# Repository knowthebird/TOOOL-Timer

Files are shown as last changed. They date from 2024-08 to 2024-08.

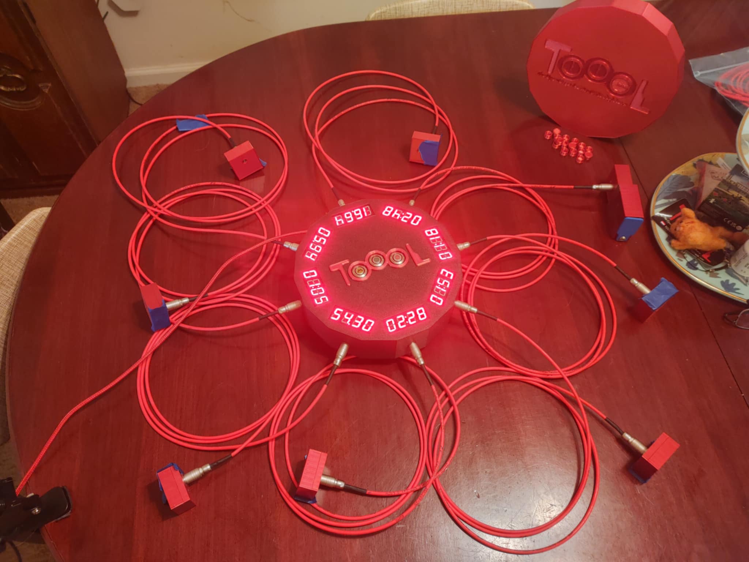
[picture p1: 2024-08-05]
Graphics/Testing-Assembly.jpg

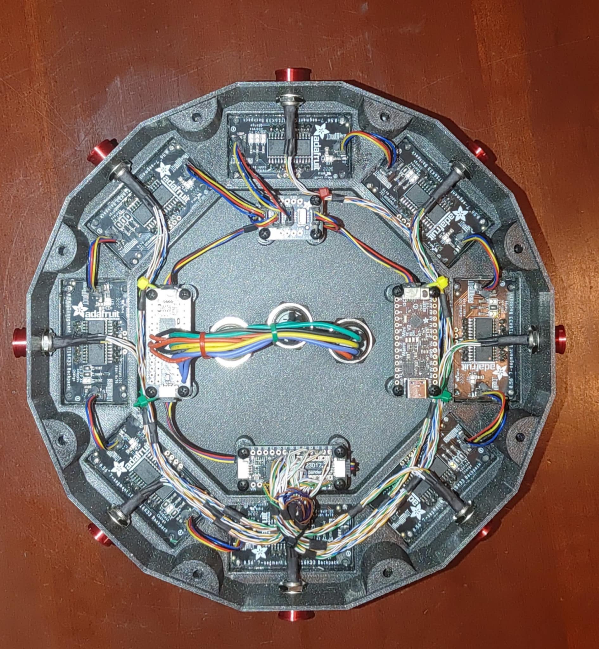
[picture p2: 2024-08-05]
Graphics/Internal-Wiring.jpg

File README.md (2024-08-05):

# TOOOL-Timer
Timer for The Open Organization Of Lockpickers (TOOOL) for Lock Picking games and competitions. 

Initially designed with TOOL DMV chapters for use with up to 8 players using TOOOLs red Kik Locks.

A youtube video covering the basics of how it works can be seen here:

Watch the video (https://youtu.be/ACWqIDEtgrU)

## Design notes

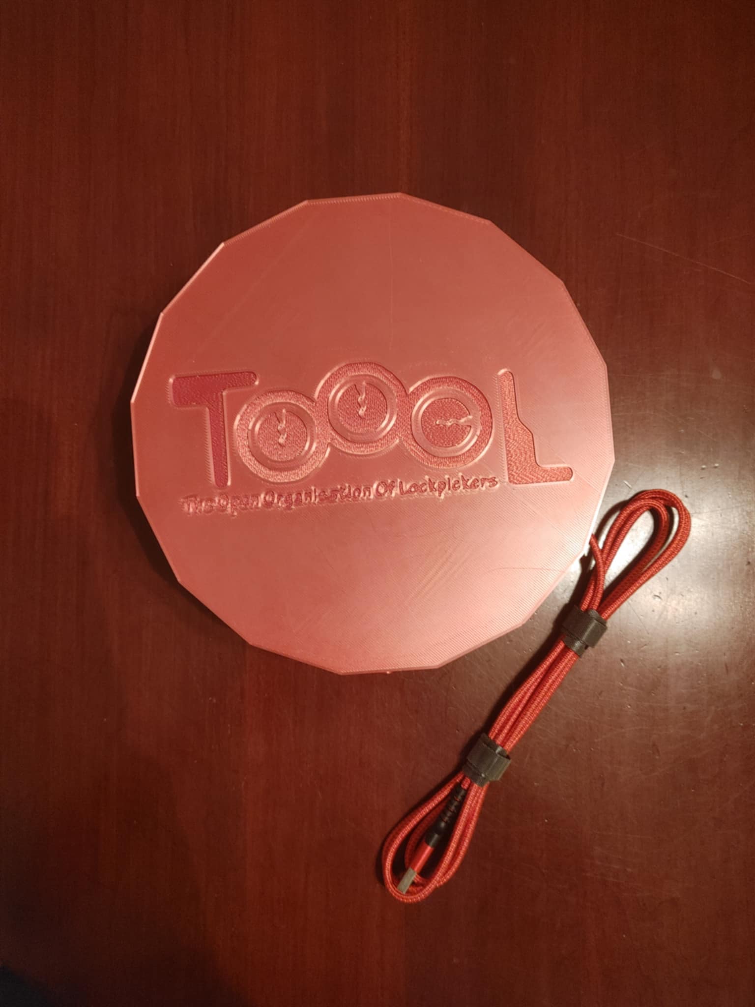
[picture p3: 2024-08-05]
Graphics/WIth-Cover.jpg

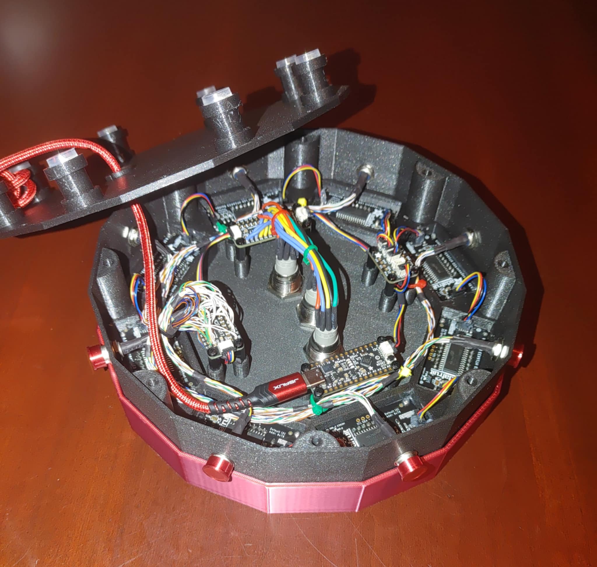
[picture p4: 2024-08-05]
Graphics/Power-Data-Cable.jpg

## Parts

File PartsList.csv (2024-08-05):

Used For | Manufacturer or Supplier Part Number | Description | Manufacturer or Supplier | Quanity | Cost per Unit | Total Cost | Link
Lock | Red KiKlock | Red KiK-lock Padlock | TOOOL | 8 | $30.00 | $240.00 | https://www.toool.us/equipment/Red-KiK-lock-p519912395/
Timer | 5625 | Qwiic / Stemma QT 5 Port Hub | Adafruit | 1 | $2.50 | $2.50 | https://www.adafruit.com/product/5625
Timer | 5346 | MCP23017 I2C GPIO Expander Breakout - STEMMA QT / Qwiic | Adafruit | 2 | $5.95 | $11.90 | https://www.adafruit.com/product/5346
Timer | 559 | Rugged Metal Pushbutton with Red LED Ring - 16mm | Adafruit | 3 | $4.95 | $14.85 | https://www.adafruit.com/product/559
Timer | 2590 | Metro Mini 328 V2 - Arduino-Compatible - 5V 16MHz | Adafruit | 1 | $14.95 | $14.95 | https://www.adafruit.com/product/2590
Timer | 877 | 7-Segment LED Matrix Backpack - STEMMA QT / qwiic | Adafruit | 8 | $6.95 | $55.60 | https://www.adafruit.com/product/877
Timer | 865 | Red 7-segment clock display - 0.56" digit height | Adafruit | 8 | $3.95 | $31.60 | https://www.adafruit.com/product/865
Timer | 4210 | STEMMA QT / Qwiic JST SH 4-pin Cable - 100mm Long | Adafruit | 3 | $0.95 | $2.85 | https://www.adafruit.com/product/4210
Timer | 4399 | STEMMA QT / Qwiic JST SH 4-Pin Cable - 50mm Long | Adafruit | 8 | $0.95 | $7.60 | https://www.adafruit.com/product/4399
Lock | HR10-7R-4SA(73) | CONN RCPT FMALE 4POS GOLD SOLDER | Hirose | 8 | $15.55 | $124.40 | https://www.digikey.com/en/products/detail/hirose-electric-co-ltd/HR10-7R-4SA-73/
Timer | HR10-7R-4S(73) | CONN RCPT FMALE 4P GOLD SLDR CUP | Hirose | 8 | $16.26 | $130.08 | https://www.digikey.com/en/products/detail/hirose-electric-co-ltd/HR10-7R-4S-73/1095427
Cables | HR10-7P-4P(73) | CONN PLUG MALE 4P GOLD SLDR CUP | Hirose | 16 | $14.61 | $233.76 | https://www.digikey.com/en/products/detail/hirose-electric-co-ltd/HR10-7P-4P-73/896581
Cables / Timer | MM-C6R-06.5-28LSZH-F | THIN CAT6 28AWG UTP LSZH 6.5 RED | Pactech | 12 | $8.11 | $97.32 | https://www.digikey.com/en/products/detail/pactech/MM-C6R-06-5-28LSZH-F/14005003
Lock | D2A-1110 | SWITCH SNAP ACTION SPDT 0.1A 30V | Omron Electronics | 8 | $1.77 | $14.16 | https://www.digikey.com/en/products/detail/omron-electronics-inc-emc-div/D2A-1110/699999
Lock | Lock Switch PCB | PCB for Lock Switch and Connector (set of 8+1 spare) | OSH Park | 1 | $4.20 | $4.20 | https://oshpark.com/shared_projects/PHDMdzFt
Timer | TYCNZ-2 | USB A to USB C Charger Cord 3.1A Fast Charging 2-Pack 6.6ft | JAUX | 1 | $6.92 | $6.92 | https://www.amazon.com/gp/product/B076FPGWNZ
Timer | DS-WSD300 | Clear Self Adhesive Rubber Bumpers Pads 13mm diameter x 4mm | Amazon | 8 | $0.04 | $0.32 | https://www.amazon.com/dp/B087MG3G76/
Timer | B0BK18R23P | Nylon Standoff Male to Female M2.5 10mm+6mm Black | Amazon | 16 | $0.20 | $3.20 | https://www.amazon.com/dp/B0BK18R23P
Timer | 92492A711 | Nylon Pan Head Phillips Screw M2.5 x 6mm Black | McMASTER-CARR | 16 | $0.02 | $0.32 | https://www.mcmaster.com/92492A711
Timer | 90925A148 | Torx Rounded Head Screw Number 6 Size 1/2" Long | McMASTER-CARR | 8 | $0.20 | $1.60 | https://www.mcmaster.com/90925A148/
Timer | 93802A221 | 18-8 Pan Head Phillips Screw 0-80 Thread 1/4" Long | McMASTER-CARR | 32 | $0.07 | $2.24 | https://www.mcmaster.com/91772A055/
Lock | 91292A115 | 18-8 Socket Head Screw M3 x 0.5 mm 16 mm Long | McMASTER-CARR | 8 | $0.07 | $0.57 | https://www.mcmaster.com/91292A115/
Lock | 91828A211 | 18-8 Hex Nut M3 x 0.5 mm Thread | McMASTER-CARR | 8 | $0.05 | $0.40 | https://www.mcmaster.com/91828A211/
Timer | Timer-Assembly-Casing | Main casing for timer and electronics | NA - 3D Printed | 1 | - | - | -
Timer | Timer-Assembly-Casing-Logo-Insert | TOOOL Logo insert for main casing | NA - 3D Printed | 2 | - | - | -
Timer | Timer-Assembly-Floor-Panel | Floor panel to seal main casing | NA - 3D Printed | 1 | - | - | -
Timer | Timer-Assembly-Floor-Panel-Grommet | Grommet to place on power cable and into floor panel | NA - 3D Printed | 2 | - | - | -
Timer | Timer-Assembly-Casing-Lid-Cover | Cover to protect top of casing surface in transit | NA - 3D Printed | 1 | - | - | -
Lock | Lock-Assembly-Shackle-Side | Lock casing covering shackle | NA - 3D Printed | 8 | - | - | -
Lock | Lock-Assembly-Connector-Side | Lock casing covering connector | NA - 3D Printed | 8 | - | - | -
Lock / Timer | Receptacle-Cover | Covers to protect receptacles when not in use | NA - 3D Printed | 16 | - | - | -
Cables / Timer | MP-H002-04-156 | Assorted Sizes of Heat Shrink Tubing | Amazon | As Needed | - | $8.79 | https://www.amazon.com/gp/product/B07QM8249H/
Timer | B07T4SYVYG | 22 AWG Stranded Wire Kit Silicone 6 Colors 7m Each Spool | Amazon | As Needed | - | $16.95 | https://www.amazon.com/gp/product/B07T4SYVYG/
Lock / Cables / Timer | 3096525-M | Multicore Solder Wire 180 C | Loctite | As Needed | - | $56.99 | https://www.amazon.com/gp/product/B00DKF13JY/
Timer | 908570 | Clear Silicone Waterproof Sealant | Loctite | As Needed | - | $9.13 | https://www.amazon.com/dp/B0002BBX3U/
Lock / Timer | PLA-1.75-SILKY-RED | PLA Filament 1.75mm Shining Red | ZIRO | As Needed | - | $20.99 | https://www.amazon.com/gp/product/B08BG6ZPF1/
Timer | Prusament PLA Galaxy Black | PLA Filament 1.75mm Galaxy Black | PRUSA | As Needed | - | $29.99 | https://www.prusa3d.com/product/prusament-pla-prusa-galaxy-black-1kg/
 |  |  |  |  | TOTAL | $1,144.18

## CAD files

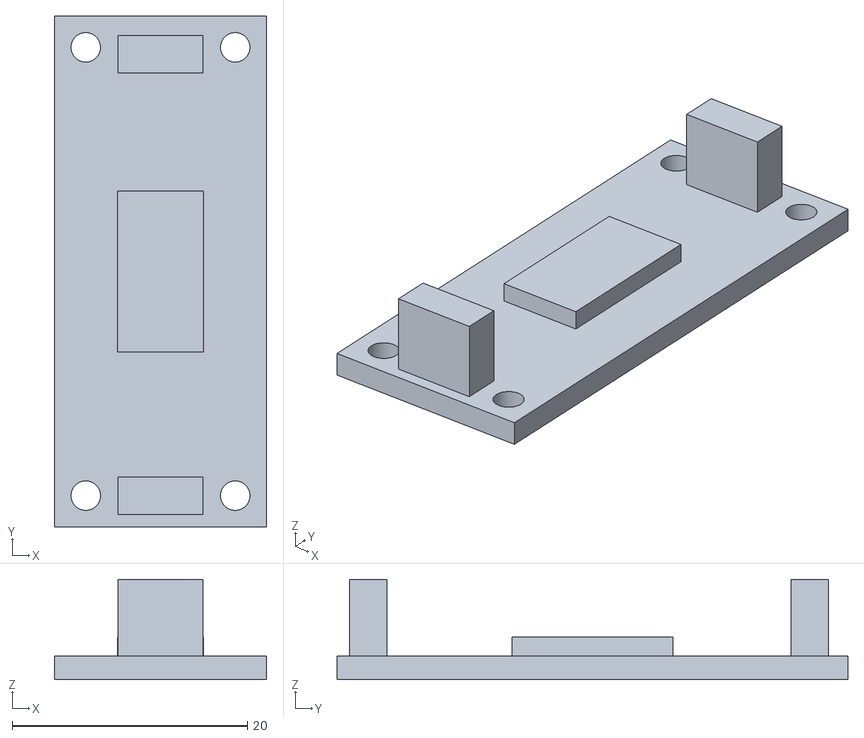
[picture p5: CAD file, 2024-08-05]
3dModels/Internal-Components/Adafruit-MCP23017-PCB-main.stl
18.0 x 43.4 x 8.50

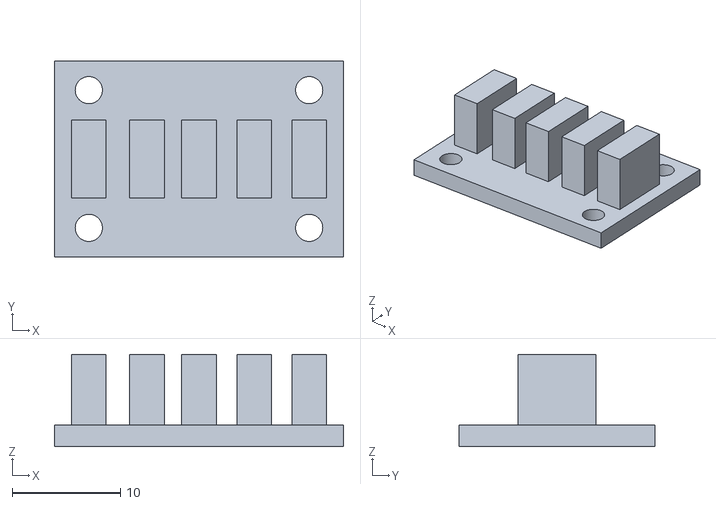
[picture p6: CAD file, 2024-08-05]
3dModels/Internal-Components/Adafruit-Qwiic-Stemma-QT-5-Port-Hub-PCB-main.stl
26.7 x 18.0 x 8.50

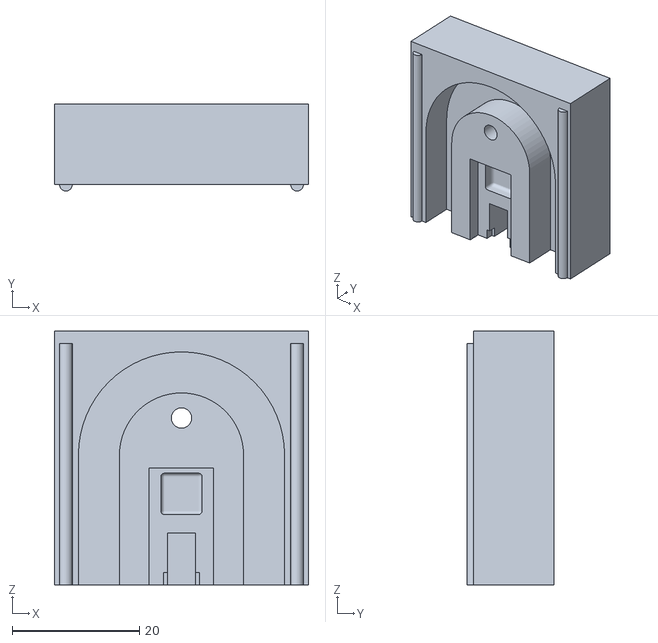
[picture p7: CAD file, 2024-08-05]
3dModels/Lock-Assembly/Shackle-Side.stl
40.0 x 13.7 x 40.0

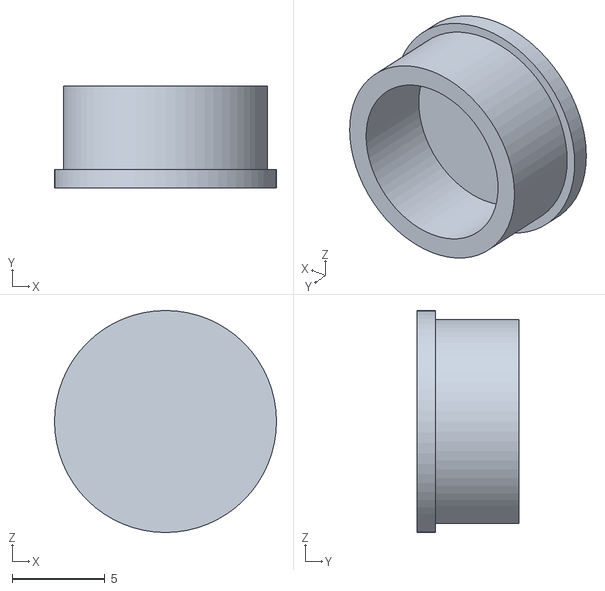
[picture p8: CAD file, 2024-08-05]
3dModels/Receptacle-Cover.stl
12.0 x 5.50 x 12.0

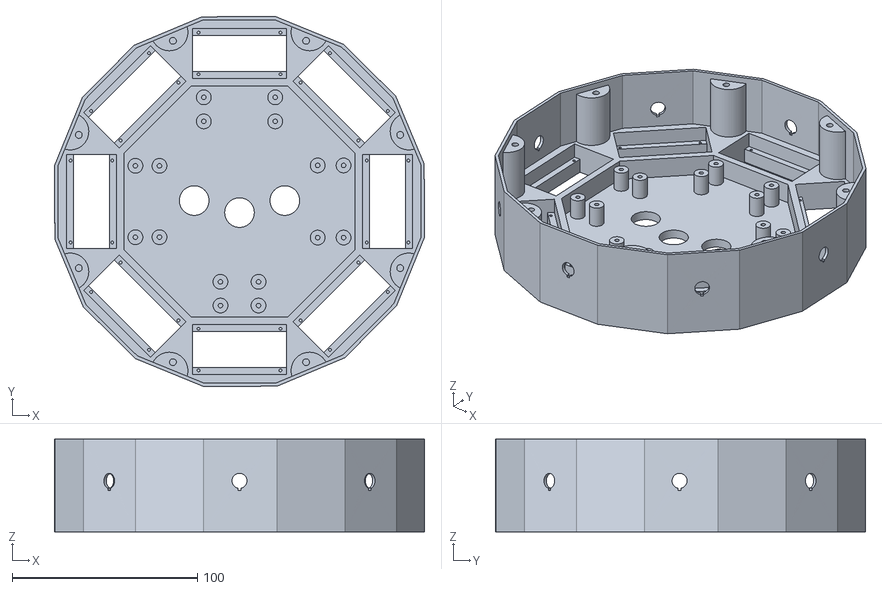
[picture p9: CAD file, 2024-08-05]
3dModels/Timer-Assembly/Casing.stl
200.0 x 200.0 x 50.0

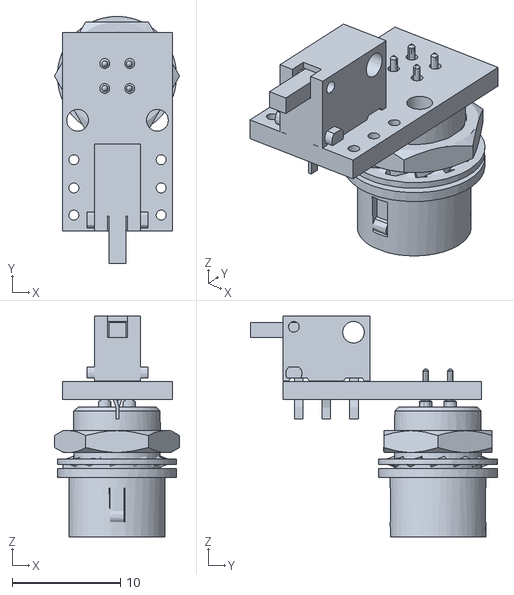
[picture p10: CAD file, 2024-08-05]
3dModels/Internal-Components/LockSwitchPCB.stl
11.5 x 22.8 x 20.4

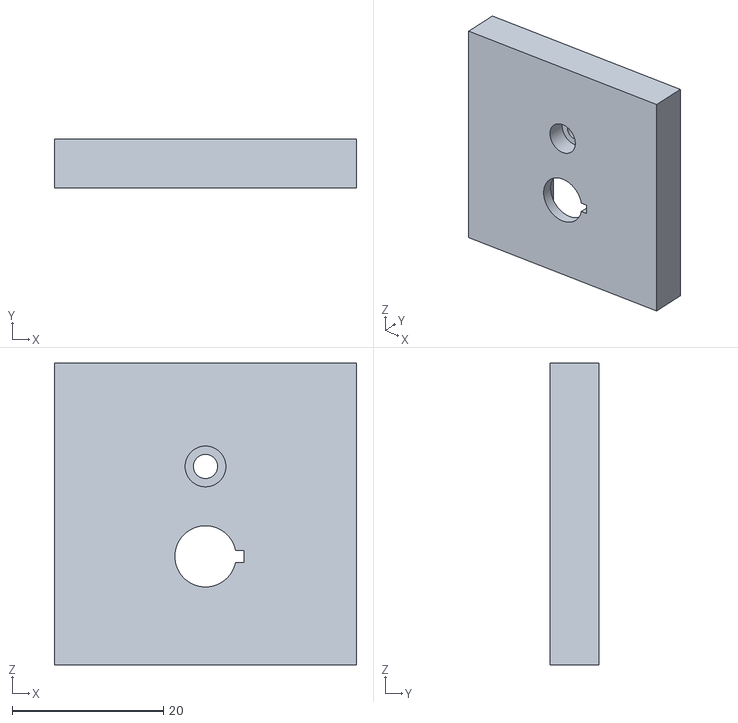
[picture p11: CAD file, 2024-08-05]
3dModels/Lock-Assembly/Connector-Side.stl
40.0 x 6.45 x 40.0

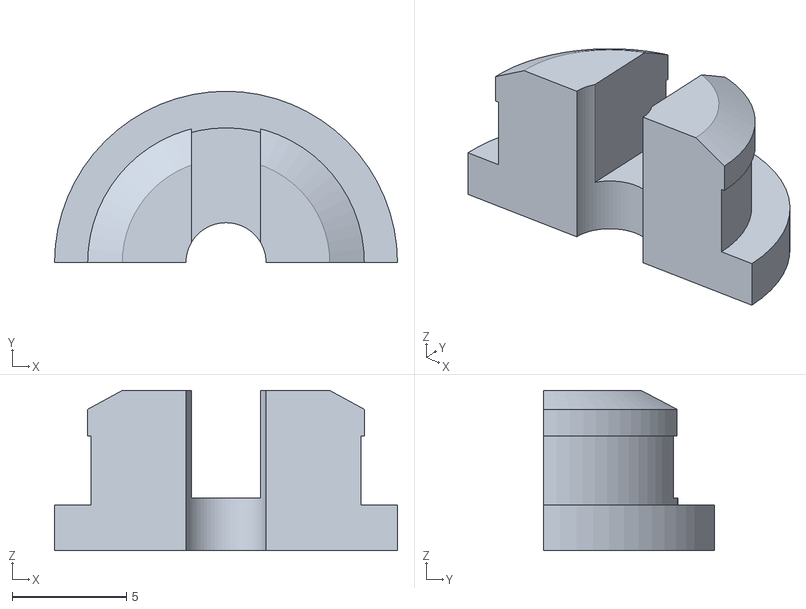
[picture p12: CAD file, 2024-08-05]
3dModels/Timer-Assembly/Floor-Panel-Grommet.stl
15.0 x 7.50 x 7.00

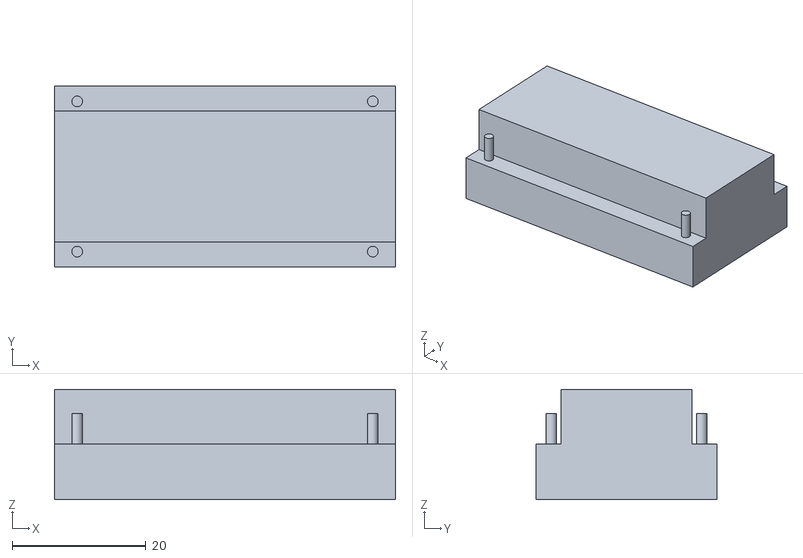
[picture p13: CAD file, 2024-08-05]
3dModels/Internal-Components/7-Seg-And-I2C-Driver-Cutout.stl
51.1 x 27.1 x 16.5

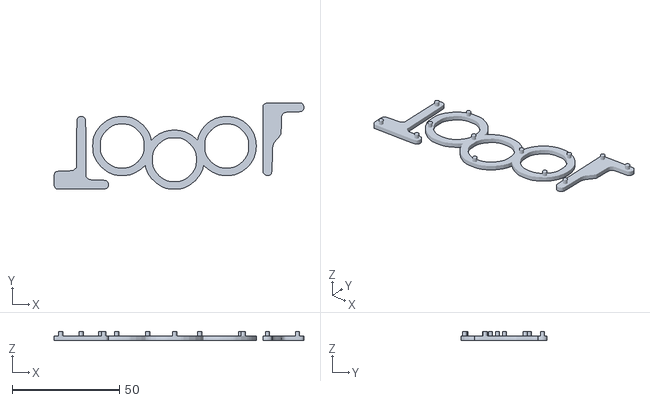
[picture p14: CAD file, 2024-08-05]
3dModels/Timer-Assembly/Casing-Logo-Insert.stl
116.4 x 40.2 x 4.00

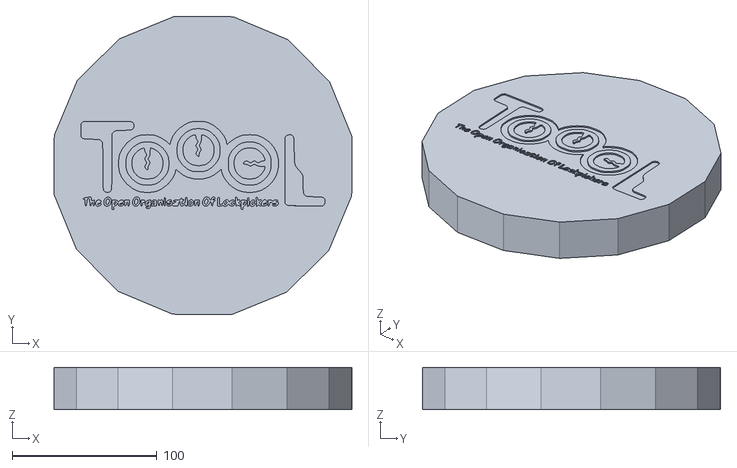
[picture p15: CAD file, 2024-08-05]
3dModels/Timer-Assembly/Casing-Lid-Cover.stl
206.0 x 206.0 x 29.3

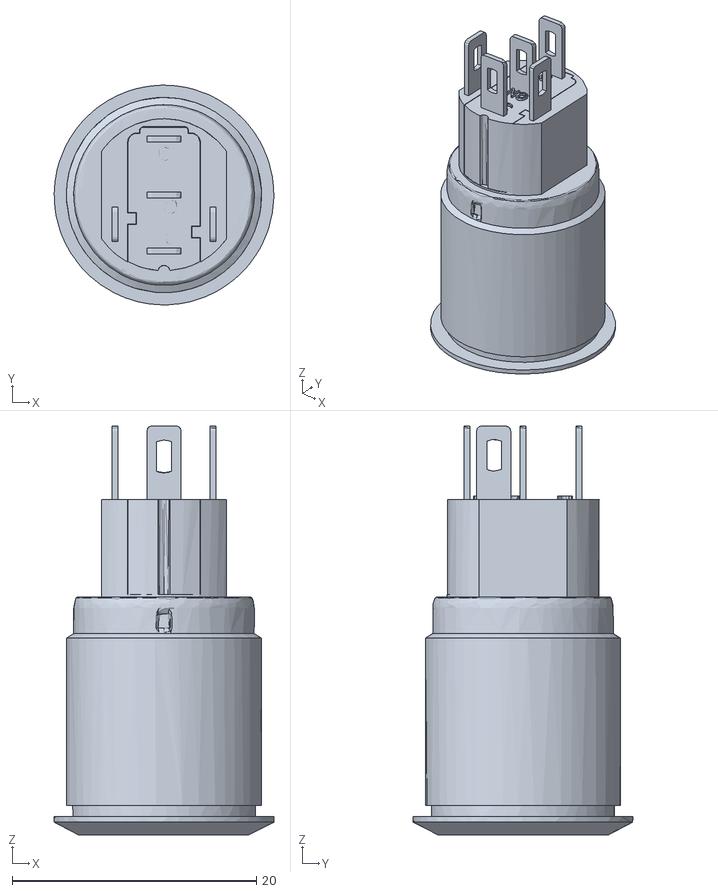
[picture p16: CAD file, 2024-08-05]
3dModels/Internal-Components/LED.stl
18.0 x 18.0 x 33.5

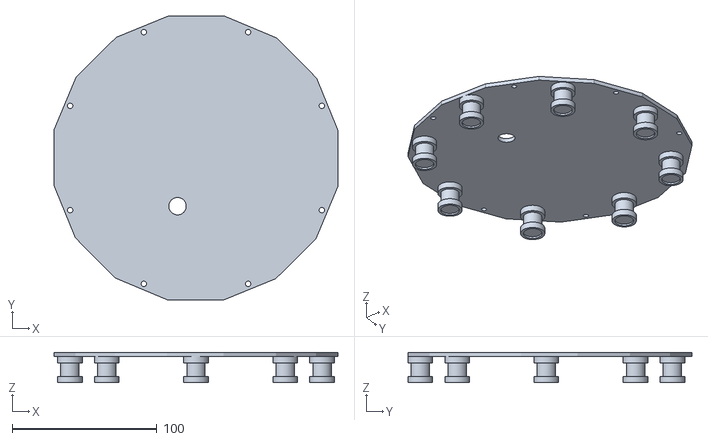
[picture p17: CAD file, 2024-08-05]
3dModels/Timer-Assembly/Floor-Panel.stl
196.0 x 196.0 x 21.0

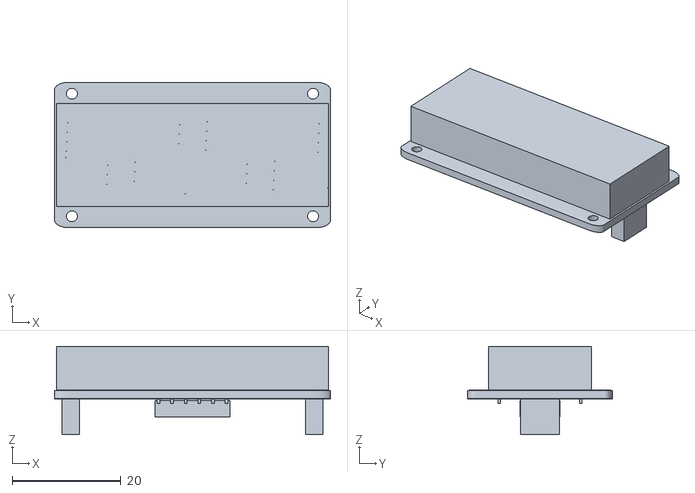
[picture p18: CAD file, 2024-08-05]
3dModels/Internal-Components/7-Seg-And-I2C-Driver.stl
50.7 x 26.7 x 16.2

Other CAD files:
3dModels/Internal-Components/Adafruit-METRO-328-PCB-master.stl
3dModels/Internal-Components/KiK-Padlock.stl
3dModels/Internal-Components/TOOOL_logo.svg_5mm.stl

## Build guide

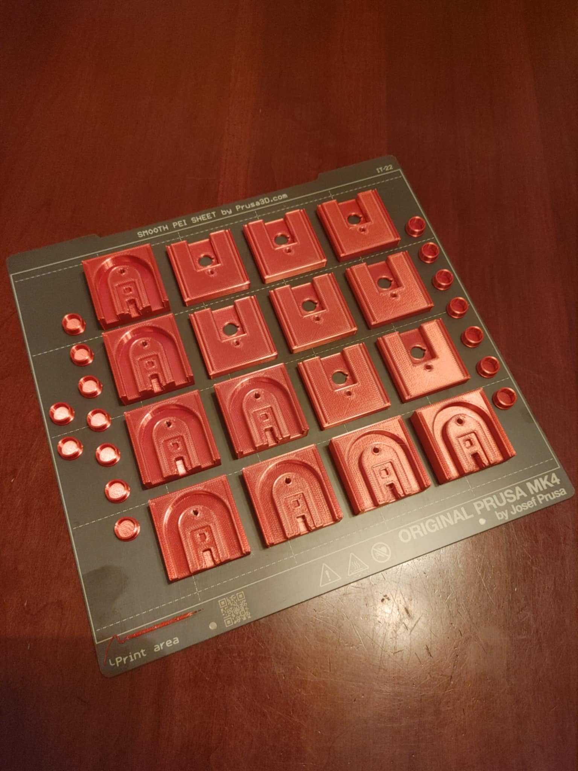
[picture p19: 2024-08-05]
Graphics/Print-Lock-Assemblies.jpg

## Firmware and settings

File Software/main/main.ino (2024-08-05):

#include <Wire.h>
#include <Adafruit_GFX.h>
#include <Adafruit_LEDBackpack.h>
#include <Adafruit_MCP23X17.h>
#include "TooolTimer.hh"
#include <Math.h>

const uint8_t ShackleOpenedLock1 = 0;  // GPA0 (21) of the MCP23017
const uint8_t ShackleOpenedLock2 = 1;  // GPA1 (22) of the MCP23017
const uint8_t ShackleOpenedLock3 = 2;  // GPA2 (23) of the MCP23017
const uint8_t ShackleOpenedLock4 = 3;  // GPA3 (24) of the MCP23017
const uint8_t ShackleOpenedLock5 = 4;  // GPA4 (25) of the MCP23017
const uint8_t ShackleOpenedLock6 = 5;  // GPA5 (26) of the MCP23017
const uint8_t ShackleOpenedLock7 = 6;  // GPA6 (27) of the MCP23017
const uint8_t ShackleOpenedLock8 = 7;  // GPA7 (28) of the MCP23017
const uint8_t ShackleClosedLock1 = 8;  // GPB0  (1) of the MCP23017
const uint8_t ShackleClosedLock2 = 9;  // GPB1  (2) of the MCP23017
const uint8_t ShackleClosedLock3 = 10; // GPB2  (3) of the MCP23017
const uint8_t ShackleClosedLock4 = 11; // GPB3  (4) of the MCP23017
const uint8_t ShackleClosedLock5 = 12; // GPB4  (5) of the MCP23017
const uint8_t ShackleClosedLock6 = 13; // GPB5  (6) of the MCP23017
const uint8_t ShackleClosedLock7 = 14; // GPB6  (7) of the MCP23017
const uint8_t ShackleClosedLock8 = 15; // GPB7  (8) of the MCP23017

const uint8_t ModeButtonLight      = 0;  // GPA0 (21) of the MCP23017
const uint8_t PlayPauseButtonLight = 1;  // GPA1 (22) of the MCP23017
const uint8_t ResetButtonLight     = 2;  // GPA2 (23) of the MCP23017
const uint8_t SpareIo1             = 3;  // GPA3 (24) of the MCP23017
const uint8_t SpareIo2             = 4;  // GPA4 (25) of the MCP23017
const uint8_t SpareIo3             = 5;  // GPA5 (26) of the MCP23017
const uint8_t SpareIo4             = 6;  // GPA6 (27) of the MCP23017
const uint8_t SpareIo5             = 7;  // GPA7 (28) of the MCP23017
const uint8_t ModeButtonNC         = 8;  // GPB0  (1) of the MCP23017
const uint8_t PlayPauseButtonNC    = 9;  // GPB1  (2) of the MCP23017
const uint8_t ResetButtonNC        = 10; // GPB2  (3) of the MCP23017
const uint8_t ModeButtonNO         = 11; // GPB3  (4) of the MCP23017
const uint8_t PlayPauseButtonNO    = 12; // GPB4  (5) of the MCP23017
const uint8_t ResetButtonNO        = 13; // GPB5  (6) of the MCP23017
const uint8_t SpareIo12            = 14; // GPB6  (7) of the MCP23017
const uint8_t SpareIo13            = 15; // GPB7  (8) of the MCP23017

Adafruit_MCP23X17 IoExpander1;
Adafruit_MCP23X17 IoExpander2;

Button ModeButton(ModeButtonNO, ModeButtonNC);
Button PlayPauseButton(PlayPauseButtonNO, PlayPauseButtonNC);
Button ResetButton(ResetButtonNO, ResetButtonNC, INPUT_PULLUP, 2000);

const uint8_t Disp_Addr[8] = {0x70, 0x71, 0x72, 0x73, 0x74, 0x75, 0x76, 0x77};
Adafruit_7segment Display[8] = Adafruit_7segment();

Timer TooolTimer;

uint32_t last_msg_change_time_;
uint8_t msg_number_to_send;

void setup() {
  Serial.begin(115200);
  Serial.println("The Open Organization Of Lockpickers (TOOOL) timer.");
  Serial.println("Starting...");
  for (int i = 0; i < 8; i++) {
    if (!Display[i].begin(Disp_Addr[i])) {
      Serial.print("Failed to start Display: ");
      Serial.println(i);
      while (1);
    } else {
      Display[i].print("8888");
      Display[i].drawColon(true);
      Display[i].writeDisplay(); 
    }
  }
  if (IoExpander1.begin_I2C(0x20)) {
    IoExpander1.pinMode(ModeButtonLight,         OUTPUT);
    IoExpander1.pinMode(PlayPauseButtonLight,    OUTPUT);
    IoExpander1.pinMode(ResetButtonLight,        OUTPUT);
    IoExpander1.pinMode(SpareIo1,          INPUT_PULLUP);
    IoExpander1.pinMode(SpareIo2,          INPUT_PULLUP);
    IoExpander1.pinMode(SpareIo3,          INPUT_PULLUP);
    IoExpander1.pinMode(SpareIo4,          INPUT_PULLUP);
    IoExpander1.pinMode(SpareIo5,          INPUT_PULLUP);
    IoExpander1.pinMode(ModeButtonNC,      INPUT_PULLUP);
    IoExpander1.pinMode(PlayPauseButtonNC, INPUT_PULLUP);
    IoExpander1.pinMode(ResetButtonNC,     INPUT_PULLUP);
    IoExpander1.pinMode(ModeButtonNO,      INPUT_PULLUP);
    IoExpander1.pinMode(PlayPauseButtonNO, INPUT_PULLUP);
    IoExpander1.pinMode(ModeButtonNO,      INPUT_PULLUP);
    IoExpander1.pinMode(SpareIo12,         INPUT_PULLUP);
    IoExpander1.pinMode(SpareIo13,         INPUT_PULLUP);

    IoExpander1.digitalWrite(ModeButtonLight, HIGH);
    IoExpander1.digitalWrite(PlayPauseButtonLight, HIGH);
    IoExpander1.digitalWrite(ResetButtonLight, HIGH);
    
    Serial.print("IoExpander1: ");
    Serial.println(IoExpander1.readGPIOAB());
  } else {
    Serial.println("Failed to start IoExpander1.");
    while (1);
  }
  if (IoExpander2.begin_I2C(0x21)) {
    IoExpander2.pinMode(ShackleOpenedLock1, INPUT_PULLUP);
    IoExpander2.pinMode(ShackleOpenedLock2, INPUT_PULLUP);
    IoExpander2.pinMode(ShackleOpenedLock3, INPUT_PULLUP);
    IoExpander2.pinMode(ShackleOpenedLock4, INPUT_PULLUP);
    IoExpander2.pinMode(ShackleOpenedLock5, INPUT_PULLUP);
    IoExpander2.pinMode(ShackleOpenedLock6, INPUT_PULLUP);
    IoExpander2.pinMode(ShackleOpenedLock7, INPUT_PULLUP);
    IoExpander2.pinMode(ShackleOpenedLock8, INPUT_PULLUP);
    IoExpander2.pinMode(ShackleClosedLock1, INPUT_PULLUP);
    IoExpander2.pinMode(ShackleClosedLock2, INPUT_PULLUP);
    IoExpander2.pinMode(ShackleClosedLock3, INPUT_PULLUP);
    IoExpander2.pinMode(ShackleClosedLock4, INPUT_PULLUP);
    IoExpander2.pinMode(ShackleClosedLock5, INPUT_PULLUP);
    IoExpander2.pinMode(ShackleClosedLock6, INPUT_PULLUP);
    IoExpander2.pinMode(ShackleClosedLock7, INPUT_PULLUP);
    IoExpander2.pinMode(ShackleClosedLock8, INPUT_PULLUP);
    Serial.print("IoExpander2: ");
    Serial.println(IoExpander2.readGPIOAB());
  } else {
    Serial.println("Failed to start IoExpander2.");
    while (1);
  }

  TooolTimer.Initialize();
  
  Serial.println("Startup Success");

  delay(3000);
  for (int i = 0; i <8; i++) {
    Display[i].clear();
    Display[i].writeDisplay();
  }

  last_msg_change_time_ = millis();
  msg_number_to_send = 1;
}

void DisplayTimeDetailed(uint8_t idx, LockState* lock_states) {
  double temp = lock_states[idx].lock_time / (1000.0*60.0*60.0);
  uint8_t time_hour = (uint8_t)temp;
  
  temp = fmod(temp,1.0) * 60.0;
  uint8_t time_min = (uint8_t)temp;

  temp = fmod(temp,1.0) * 60.0;
  uint8_t time_sec = (uint8_t)temp;

  temp = fmod(temp,1.0) * 100.0;
  uint8_t time_centisec = (uint8_t)temp;
   
  if (time_hour >= 1) {
    Display[idx].drawColon(true);
    if (time_hour < 10) {
      Display[idx].writeDigitNum(0, 0);
      Display[idx].writeDigitNum(1, time_hour);
    } else {
      Display[idx].writeDigitNum(0, (uint8_t)(time_hour / 10));
      Display[idx].writeDigitNum(1, (uint8_t)(time_hour % 10));
    }
    if (time_min < 10) {
      Display[idx].writeDigitNum(3, 0);
      Display[idx].writeDigitNum(4, time_min);
    } else {
      Display[idx].writeDigitNum(3, (uint8_t)(time_min / 10));
      Display[idx].writeDigitNum(4, (uint8_t)(time_min % 10));
    }
  } else if (time_min >= 1) {
    Display[idx].drawColon(true);
    if (time_min < 10) {
      Display[idx].writeDigitNum(0, 0);
      Display[idx].writeDigitNum(1, time_min);
    } else {
      Display[idx].writeDigitNum(0, (uint8_t)(time_min / 10));
      Display[idx].writeDigitNum(1, (uint8_t)(time_min % 10));
    }
    if (time_sec < 10) {
      Display[idx].writeDigitNum(3, 0);
      Display[idx].writeDigitNum(4, time_sec);
    } else {
      Display[idx].writeDigitNum(3, (uint8_t)(time_sec / 10));
      Display[idx].writeDigitNum(4, (uint8_t)(time_sec % 10));
    }
  } else {
    if (time_sec < 10) {
      Display[idx].writeDigitNum(0, 0);
      Display[idx].writeDigitNum(1, time_sec, true);
    } else {
      Display[idx].writeDigitNum(0, (uint8_t)(time_sec / 10));
      Display[idx].writeDigitNum(1, (uint8_t)(time_sec % 10), true);
    }
    if (time_centisec < 10) {
      Display[idx].writeDigitNum(3, 0);
      Display[idx].writeDigitNum(4, time_centisec);
    } else {
      Display[idx].writeDigitNum(3, (uint8_t)(time_centisec / 10));
      Display[idx].writeDigitNum(4, (uint8_t)(time_centisec % 10));
    }
  }
}

void loop() {
  uint16_t button_states = IoExpander1.readGPIOAB();
  uint16_t lock_switches = IoExpander2.readGPIOAB();

  if (ModeButton.IsPressed(button_states)) {
    IoExpander1.digitalWrite(ModeButtonLight, HIGH);
  } else {
    IoExpander1.digitalWrite(ModeButtonLight, LOW);
  }
  if (PlayPauseButton.IsPressed(button_states)) {
    IoExpander1.digitalWrite(PlayPauseButtonLight, HIGH);
  } else {
    IoExpander1.digitalWrite(PlayPauseButtonLight, LOW);
  }
  if (ResetButton.IsPressed(button_states)) {
    IoExpander1.digitalWrite(ResetButtonLight, HIGH);
  } else {
    IoExpander1.digitalWrite(ResetButtonLight, LOW);
  }

  LockState* lock_states = TooolTimer.Step(lock_switches, ModeButton.IsNewPress(button_states), PlayPauseButton.IsNewPress(button_states), ResetButton.IsNewPress(button_states));

  uint32_t current_time = millis();
  if (current_time > last_msg_change_time_ + 1000) {
    last_msg_change_time_ = current_time;
    if (1 == msg_number_to_send) {
      msg_number_to_send = 2;
    } else if (2 == msg_number_to_send) {
      msg_number_to_send = 3;
    } else if (3 == msg_number_to_send) {
      msg_number_to_send = 1;
    }
  }
  
  for (int i = 0; i < 8; i++) {
    Display[i].clear();
    
    if (initial == lock_states[i].lock_mode) {
      if (msg_number_to_send / 2) {
        if (lock_states[i].is_open) {
          Display[i].println("Shut");
        } else if (lock_states[i].is_on) {
          Display[i].println("Play");
        } else {
          Display[i].println("Off");
        }
      } else {
        if (lock_states[i].is_open) {
          Display[i].println("Bolt");
        } else if (lock_states[i].is_on) {
          Display[i].println("Play");
        } else {
          Display[i].println("Off");
        }
      }
    }
    if (starting == lock_states[i].lock_mode) {
      Display[i].println(lock_states[i].lock_time/1000);
    }
    if (countup == lock_states[i].lock_mode) {
      if (!lock_states[i].is_on) {
        if (1 == msg_number_to_send) {
          Display[i].println("Bad"); 
        } else if (2 == msg_number_to_send) {
          Display[i].println("Line"); 
        } else {
          DisplayTimeDetailed(i, lock_states);
        }
      } else {
        DisplayTimeDetailed(i, lock_states);
      }

    }
    if (complete == lock_states[i].lock_mode) {
      if (1 == msg_number_to_send) {
        if (1 == lock_states[i].order_opened) {
          Display[i].println("1st"); 
        } else if (2 == lock_states[i].order_opened) {
          Display[i].println("2nd"); 
        } else if (3 == lock_states[i].order_opened) {
          Display[i].println("3rd"); 
        }  else if (4 == lock_states[i].order_opened) {
          Display[i].println("4th"); 
        }  else if (5 == lock_states[i].order_opened) {
          Display[i].println("5th"); 
        }  else if (6 == lock_states[i].order_opened) {
          Display[i].println("6th"); 
        }  else if (7 == lock_states[i].order_opened) {
          Display[i].println("7th"); 
        }  else if (8 == lock_states[i].order_opened) {
          Display[i].println("8th"); 
        }
      } else if (2 == msg_number_to_send) {
        Display[i].println("OPEN");
      } else {
        DisplayTimeDetailed(i, lock_states);
      }
    }
    if (lock_states[i].is_failed) {
      Display[i].println("Err"); 
    }
    Display[i].writeDisplay(); 

  }
  

}
